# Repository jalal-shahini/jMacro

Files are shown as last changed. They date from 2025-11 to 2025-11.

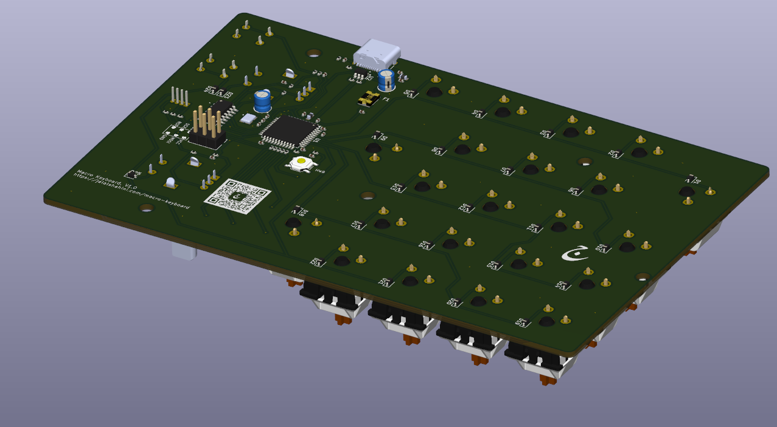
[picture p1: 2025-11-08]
3d_model_pcb_2.png

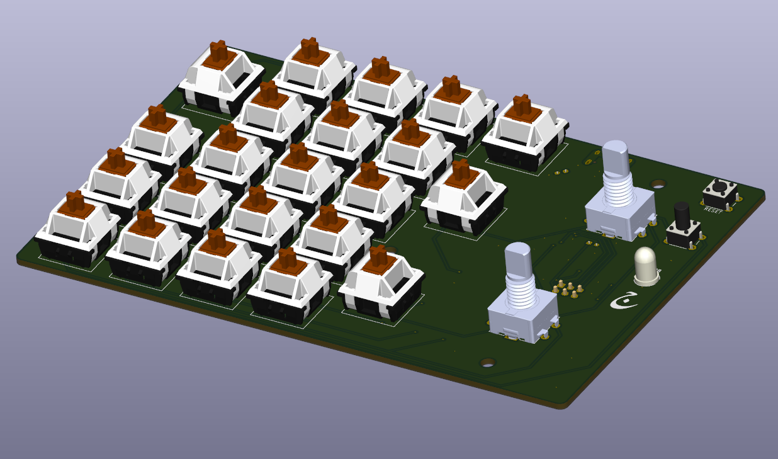
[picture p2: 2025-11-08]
3d_model_pcb.png

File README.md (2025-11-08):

# jMacro
## A Custom Built Macro Keyboard

This is a macro keyboard I designed to be:

1. a Numpad once a month when I need one.
2. an easy way to type the special characters I use constantly when taking notes such as ※, ℍ, Ω, ℚ, ∵, ∴, ℘ etc.
3. a life-saver when playing games.

The keyboard uses an Atmega32u4 microcontroller.
It features 22 keys with two rotary encoders with a Schmitt-trigger for a clean signal.

### To Do for a Future Version

* Single LED indicator is too bright and not ideal. I will use backlight LEDs for each individual key.
* Rotary encoders and USB circuit will benefit from a 4 layer PCB.
* Switches are better to be hot swappable.
* The electolytic capacitors are THT to save costs, however, in the next versions it is better to use all SMD components.

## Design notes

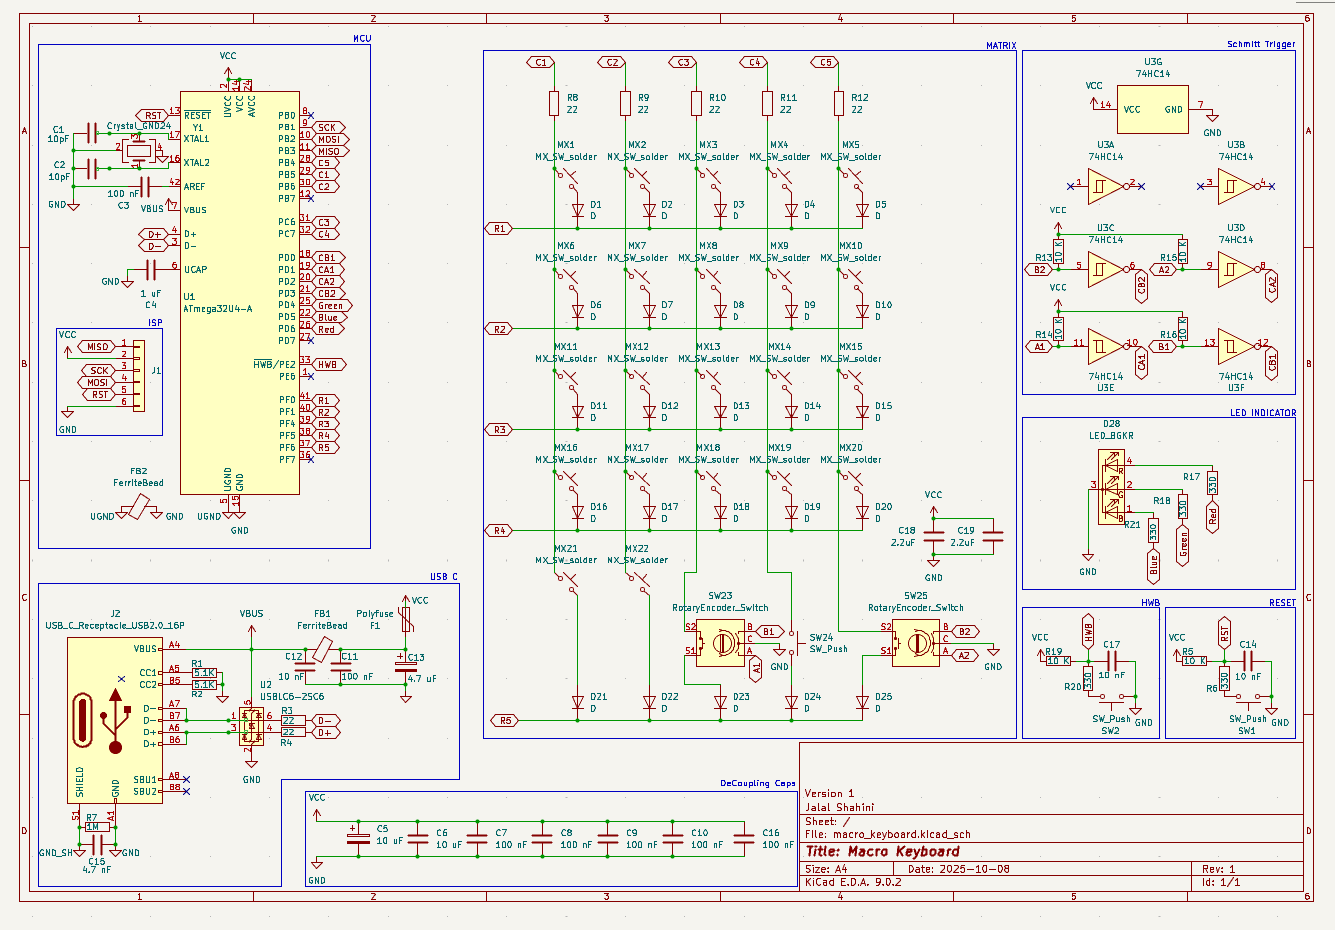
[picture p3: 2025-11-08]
schematic.png

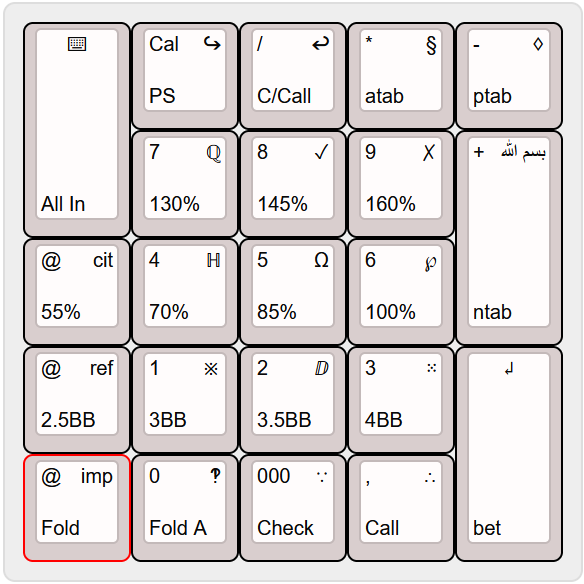
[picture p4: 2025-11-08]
layout.png

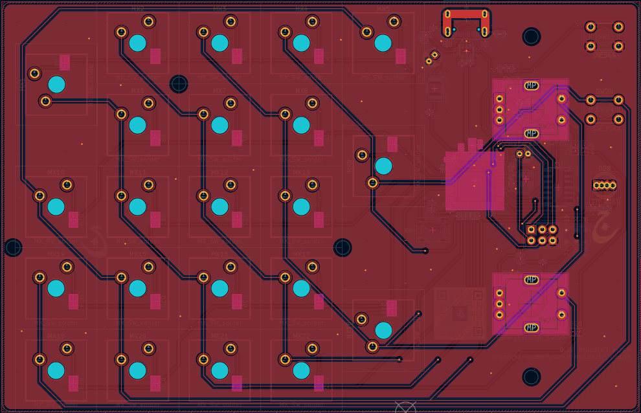
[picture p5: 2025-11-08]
top_layer.png

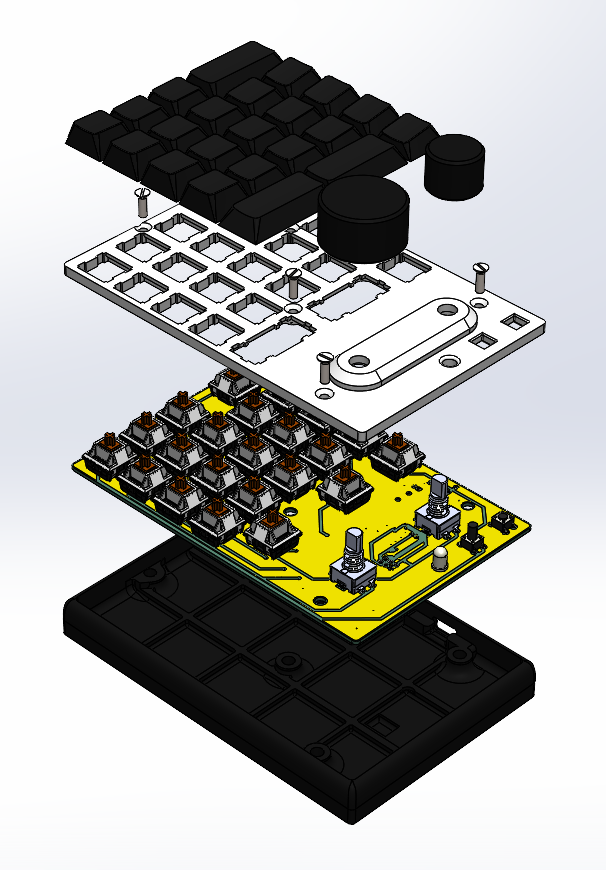
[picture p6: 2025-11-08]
exploded_view.png

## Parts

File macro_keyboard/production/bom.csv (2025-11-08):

Designator | Footprint | Quantity | Value | LCSC Part #
C1, C2 | 0402 | 2 | 10pF | C32949
C10, C11, C16, C7, C8, C9 | 0402 | 6 | 100 nF
C12 | 0402 | 1 | 10 nF
C14, C17 | 0402 | 2 | 10 nF
C15 | 0402 | 1 | 4.7 nF
C18, C19 | 0402 | 2 | 2.2uF
C3 | 0402 | 1 | 100 nF | C1525
C4 | 0402 | 1 | 1 uF
C6 | 0402 | 1 | 10 uF
D1, D10, D11, D12, D13, D14, D15, D16, D17, D18, D19, D2, D20, D21, D22, D23, D24, D25, D3, D4, D5, D6, D7, D8, D9 | D_SOD-323 | 25 | D | C2128
F1 | 1812 | 1 | Polyfuse | Manufacturer PTTC(Polytronics Tech) Copy MFR.Part # SMD1812P110TF Copy JLCPCB Part # C3102 Copy Package 1812 Copy Description -40℃~+85℃ 1.1A 100A 2.2A 210mΩ 300ms 40mΩ 800mW 8V 1812 Resettable Fuses ROHS
FB1, FB2 | BEADC1608X95N | 2 | FerriteBead | C14709
J2 | USB_C_Receptacle_HCTL_HC-TYPE-C-16P-01A | 1 | USB_C_Receptacle_USB2.0_16P | C2894897
R1, R2 | 0402 | 2 | 5.1K
R10, R11, R12, R3, R4, R8, R9 | 0402 | 7 | 22 | C25092
R13, R14, R15, R16, R19, R5 | 0402 | 6 | 10 K | C17414
R17, R18, R21 | 0402 | 3 | 330
R20, R6 | 0402 | 2 | 330 | C23138
R7 | 0402 | 1 | 1M
SW2 | SW_Push_1P1T_XKB_TS-1187A | 1 | SW_Push | C318884
U1 | TQFP-44_10x10mm_P0.8mm | 1 | ATmega32U4-A | C2052746
U2 | SOT-23-6 | 1 | USBLC6-2SC6 | C7519
U3 | SOIC-14_3.9x8.7mm_P1.27mm | 1 | 74HC14 | C5605
Y1 | OSC_X322516MLB4SI | 1 | Crystal_GND24 | C13738

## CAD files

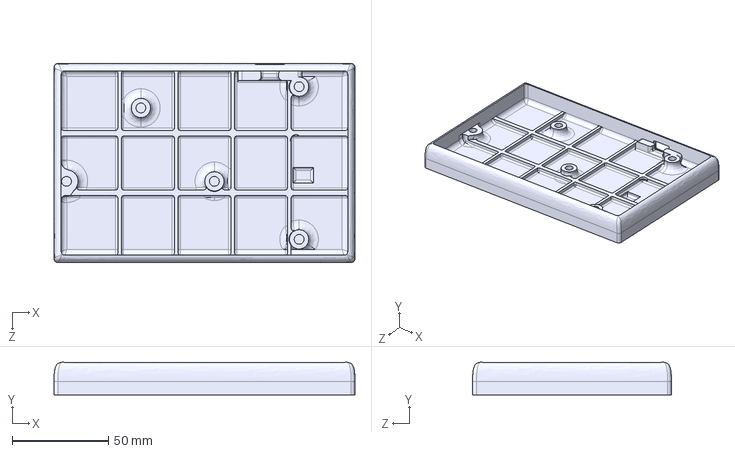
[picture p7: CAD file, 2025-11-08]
enclosure/Part2.STEP
156.3 x 17.0 x 103.2 mm

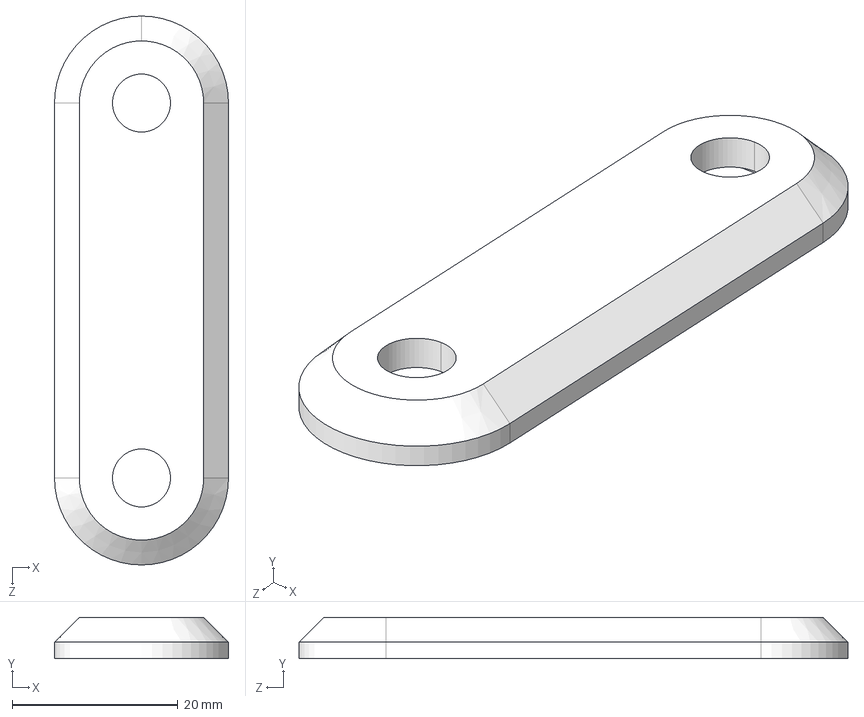
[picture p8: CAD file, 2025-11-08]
enclosure/Part3.STEP
21.0 x 5.00 x 66.2 mm

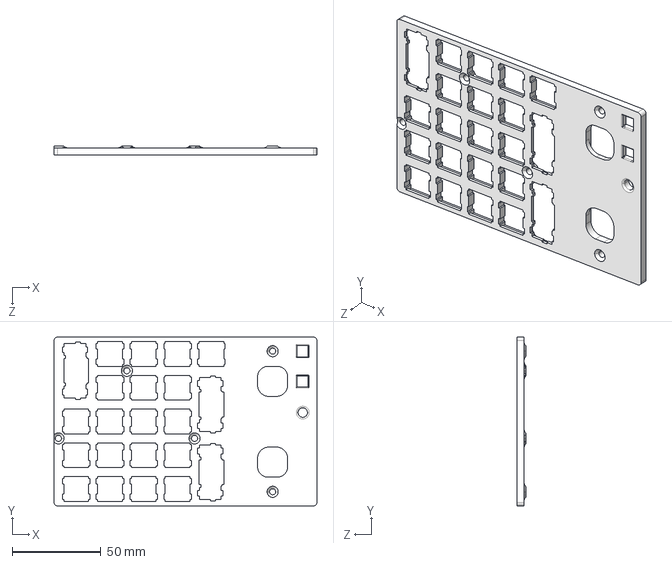
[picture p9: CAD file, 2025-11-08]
enclosure/Part1.STEP
148.3 x 95.2 x 5.00 mm

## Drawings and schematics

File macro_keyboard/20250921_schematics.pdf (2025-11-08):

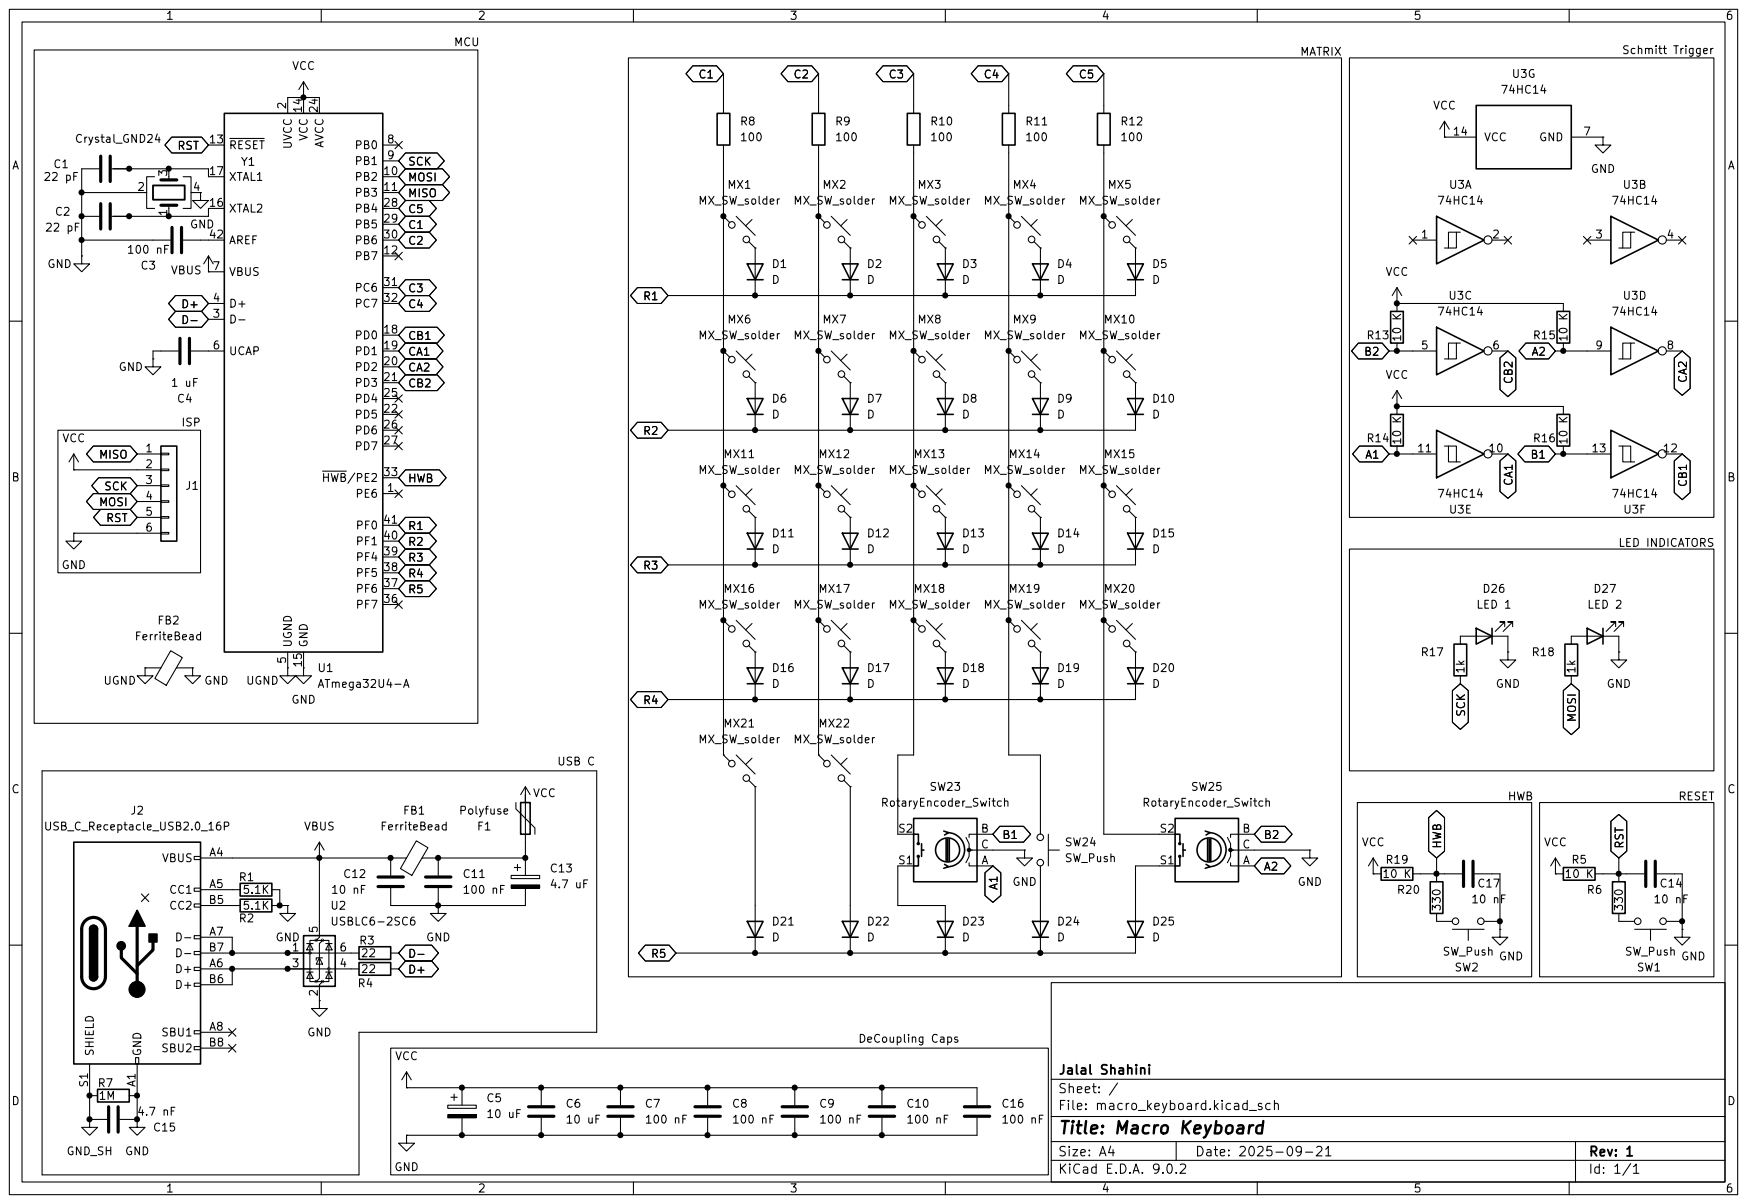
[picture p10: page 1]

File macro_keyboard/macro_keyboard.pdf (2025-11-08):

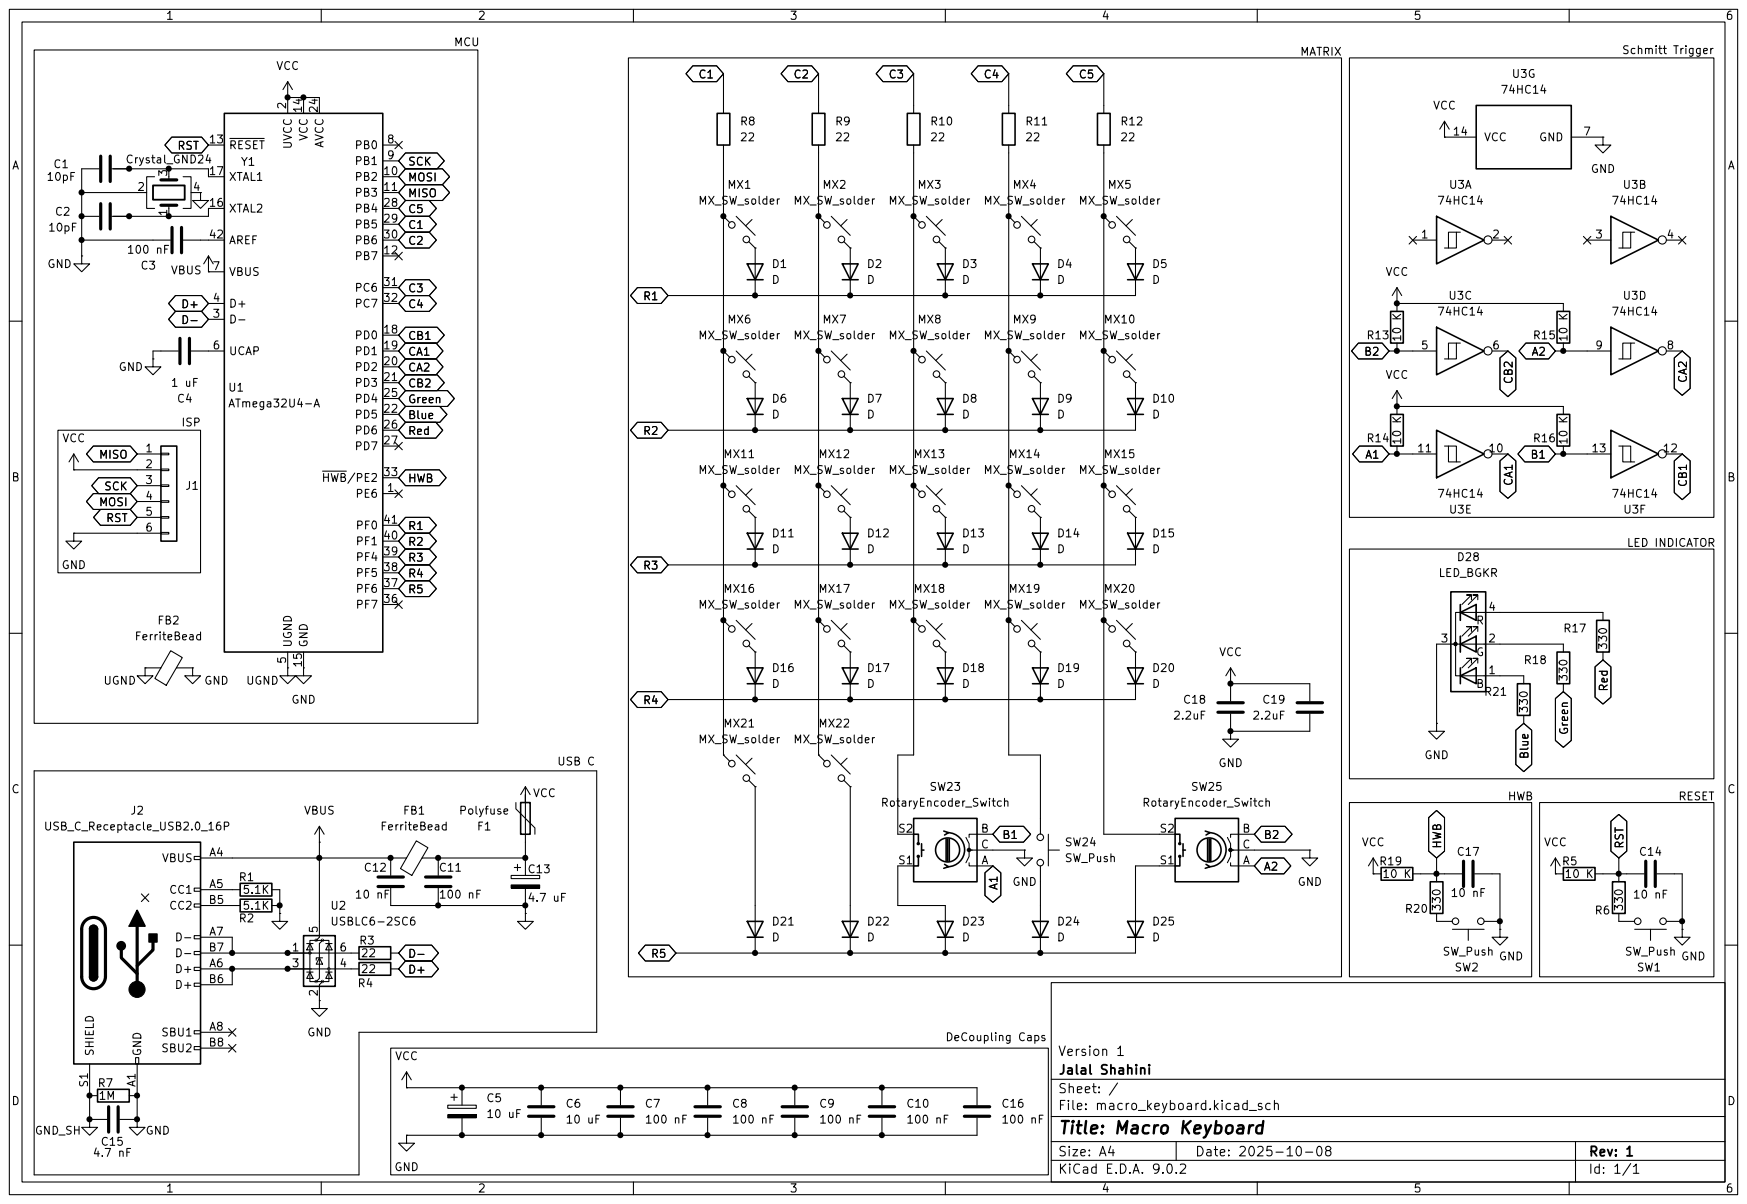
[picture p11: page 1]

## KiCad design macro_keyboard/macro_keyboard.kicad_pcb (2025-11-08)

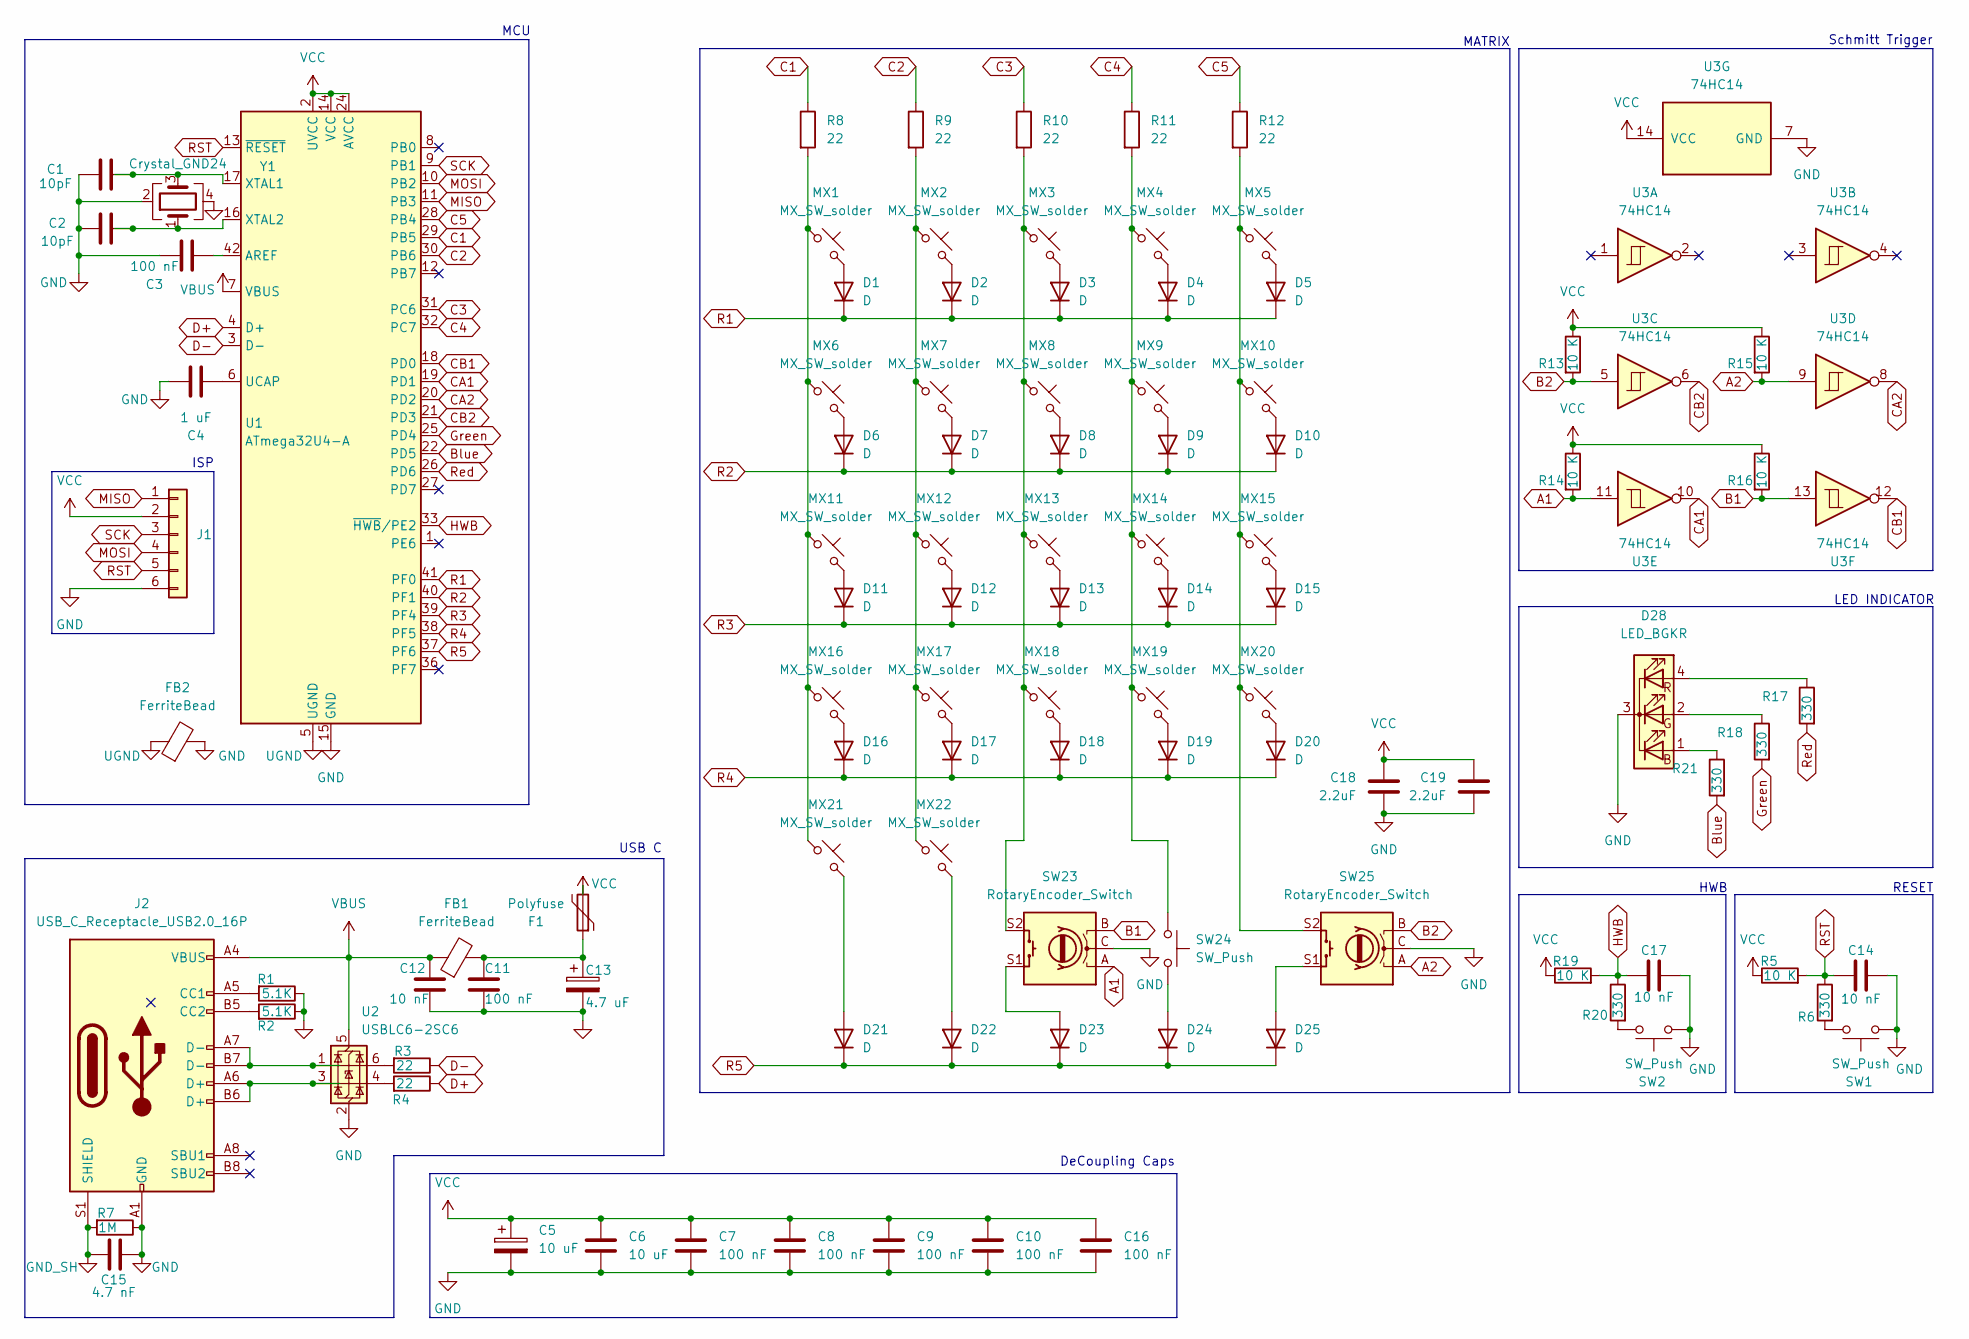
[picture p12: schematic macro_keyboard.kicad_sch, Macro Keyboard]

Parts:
C1, C2: 10pF; C_0402_1005Metric; LCSC C32949
C3, C7, C8, C9, C10, C11, C16: 100 nF; C_0402_1005Metric; LCSC C1525
C4: 1 uF; C_0402_1005Metric; LCSC C52923
C5: 10 uF; CP_Radial_D4.0mm_P2.00mm
C6: 10 uF; C_0402_1005Metric; LCSC C15525
C12, C14, C17: 10 nF; C_0402_1005Metric; LCSC C15195
C13: 4.7 uF; CP_Radial_D4.0mm_P2.00mm
C15: 4.7 nF; C_0402_1005Metric; LCSC C1538
C18, C19: 2.2uF; C_0402_1005Metric; LCSC C12530
D1, D2, D3, D4, D5, D6, D7, D8, D9, D10, D11, D12, D13, D14, D15, D16, D17, D18, D19, D20, D21, D22, D23, D24, D25: D; D_SOD-323; LCSC C2128
D28: LED_BGKR; LED_D5.0mm-4_RGB
F1: Polyfuse; Fuse_1812_4532Metric; LCSC C3102
FB1: FerriteBead; BEADC1608X95N; LCSC C14709
FB2: FerriteBead; C_0603_1608Metric; LCSC C14709
J1: Conn_01x06; PinHeader_2x03_P2.54mm_Vertical
J2: USB_C_Receptacle_USB2.0_16P; USB_C_Receptacle_HCTL_HC-TYPE-C-16P-01A; LCSC C2894897
MX1, MX2, MX3, MX4, MX5, MX6, MX7, MX8, MX9, MX10, MX11, MX12, MX13, MX14, MX15, MX16, MX17, MX18, MX19, MX20, MX21, MX22: MX_SW_solder; SW_Cherry_MX_Plate_1.00u
R1, R2: 5.1K; R_0402_1005Metric; LCSC C25905
R3, R4, R8, R9, R10, R11, R12: 22; R_0402_1005Metric; LCSC C25092
R5, R13, R14, R15, R16, R19: 10 K; R_0402_1005Metric; LCSC C25744
R6, R17, R18, R20, R21: 330; R_0402_1005Metric; LCSC C25104
R7: 1M; R_0402_1005Metric; LCSC C26083
SW1: SW_Push; SW_PUSH_6mm_H4.3mm
SW2: SW_Push; SW_Push_1P1T_XKB_TS-1187A; LCSC C318884
SW23, SW25: RotaryEncoder_Switch; RotaryEncoder_Alps_EC11E-Switch_Vertical_H20mm
SW24: SW_Push; SW_PUSH_6mm_H9.5mm
U1: ATmega32U4-A; TQFP-44_10x10mm_P0.8mm; LCSC C2052746
U2: USBLC6-2SC6; SOT-23-6; LCSC C7519
U3: 74HC14; SOIC-14_3.9x8.7mm_P1.27mm; LCSC C5605
Y1: Crystal_GND24; OSC_X322516MLB4SI; LCSC C13738

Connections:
A1: R14.2, SW23.A, U3.11
A2: R15.2, SW25.A, U3.9
B1: R16.2, SW23.B, U3.13
B2: R13.2, SW25.B, U3.5
Blue: R21.2, U1.22 (PD5)
C1: R8.1, U1.29 (PB5)
C2: R9.1, U1.30 (PB6)
C3: R10.1, U1.31 (PC6)
C4: R11.1, U1.32 (PC7)
C5: R12.1, U1.28 (PB4)
CA1: U1.19 (PD1), U3.10
CA2: U1.20 (PD2), U3.8
CB1: U1.18 (PD0), U3.12
CB2: U1.21 (PD3), U3.6
D+: R4.1, U1.4 (D+)
D-: R3.1, U1.3 (D-)
GND: C1.1, C2.1, C3.1, C4.2, C5.2, C6.2, C7.2, C8.2, C9.2, C10.2, C11.2, C12.2, C13.2, C14.2, C15.2, C16.2, C17.2, C18.2, C19.2, D28.3 (K), FB2.2, J1.6, J2.A1 (GND), J2.A12 (GND), J2.B1 (GND), J2.B12 (GND), R1.1, R2.1, R7.1, SW1.2, SW2.2, SW23.C, SW25.C, U1.15 (GND), U1.23 (GND), U1.35 (GND), U1.43 (GND), U2.2 (GND), U3.7 (GND), Y1.2, Y1.4
GND_SH: C15.1, J2.S1 (SHIELD), R7.2
Green: R18.2, U1.25 (PD4)
HWB: C17.1, R19.2, R20.1, U1.33 (~HWB/PE2)
MISO: J1.1, U1.11 (PB3)
MOSI: J1.4, U1.10 (PB2)
unnamed: C11.1, C13.1, F1.1, FB1.2
unnamed: D1.2 (A), MX1.2
unnamed: D2.2 (A), MX2.2
unnamed: D3.2 (A), MX3.2
unnamed: D4.2 (A), MX4.2
unnamed: D5.2 (A), MX5.2
unnamed: D6.2 (A), MX6.2
unnamed: D7.2 (A), MX7.2
unnamed: D8.2 (A), MX8.2
unnamed: D9.2 (A), MX9.2
unnamed: D10.2 (A), MX10.2
unnamed: D11.2 (A), MX11.2
unnamed: D12.2 (A), MX12.2
unnamed: D13.2 (A), MX13.2
unnamed: D14.2 (A), MX14.2
unnamed: D15.2 (A), MX15.2
unnamed: D16.2 (A), MX16.2
unnamed: D17.2 (A), MX17.2
unnamed: D18.2 (A), MX18.2
unnamed: D19.2 (A), MX19.2
unnamed: D20.2 (A), MX20.2
unnamed: D21.2 (A), MX21.2
unnamed: D22.2 (A), MX22.2
unnamed: D23.2 (A), SW23.S1
unnamed: D24.2 (A), SW24.2
unnamed: D25.2 (A), SW25.S1
unnamed: D28.1 (BA), R21.1
unnamed: D28.2 (GA), R18.1
unnamed: D28.4 (RA), R17.1
unnamed: J2.A5 (CC1), R1.2
unnamed: J2.B5 (CC2), R2.2
unnamed: J2.A6 (D+), J2.B6 (D+), U2.3 (I/O2)
unnamed: J2.A7 (D-), J2.B7 (D-), U2.1 (I/O1)
unnamed: MX1.1, MX6.1, MX11.1, MX16.1, MX21.1, R8.2
unnamed: MX5.1, MX10.1, MX15.1, MX20.1, R12.2, SW25.S2
unnamed: MX2.1, MX7.1, MX12.1, MX17.1, MX22.1, R9.2
unnamed: MX3.1, MX8.1, MX13.1, MX18.1, R10.2, SW23.S2
unnamed: MX4.1, MX9.1, MX14.1, MX19.1, R11.2, SW24.1
unnamed: R3.2, U2.6 (I/O1)
unnamed: R4.2, U2.4 (I/O2)
unnamed: R6.2, SW1.1
unnamed: R20.2, SW2.1
unnamed: C3.2, U1.42 (AREF)
unnamed: C4.1, U1.6 (UCAP)
unnamed: C1.2, U1.17 (XTAL1), Y1.3
unnamed: C2.2, U1.16 (XTAL2), Y1.1
R1: D1.1 (K), D2.1 (K), D3.1 (K), D4.1 (K), D5.1 (K), U1.41 (PF0)
R2: D6.1 (K), D7.1 (K), D8.1 (K), D9.1 (K), D10.1 (K), U1.40 (PF1)
R3: D11.1 (K), D12.1 (K), D13.1 (K), D14.1 (K), D15.1 (K), U1.39 (PF4)
R4: D16.1 (K), D17.1 (K), D18.1 (K), D19.1 (K), D20.1 (K), U1.38 (PF5)
R5: D21.1 (K), D22.1 (K), D23.1 (K), D24.1 (K), D25.1 (K), U1.37 (PF6)
RST: C14.1, J1.5, R5.2, R6.1, U1.13 (~RESET)
Red: R17.2, U1.26 (PD6)
SCK: J1.3, U1.9 (PB1)
UGND: FB2.1, U1.5 (UGND)
VBUS: C12.1, FB1.1, J2.A4 (VBUS), J2.A9 (VBUS), J2.B4 (VBUS), J2.B9 (VBUS), U1.7 (VBUS), U2.5 (VBUS)
VCC: C5.1, C6.1, C7.1, C8.1, C9.1, C10.1, C16.1, C18.1, C19.1, F1.2, J1.2, R5.1, R13.1, R14.1, R15.1, R16.1, R19.1, U1.2 (UVCC), U1.14 (VCC), U1.24 (AVCC), U1.34 (VCC), U1.44 (AVCC), U3.14 (VCC)

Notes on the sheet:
RESET
HWB
DeCoupling Caps
ISP
USB C
MATRIX
MCU
Schmitt Trigger
LED INDICATOR

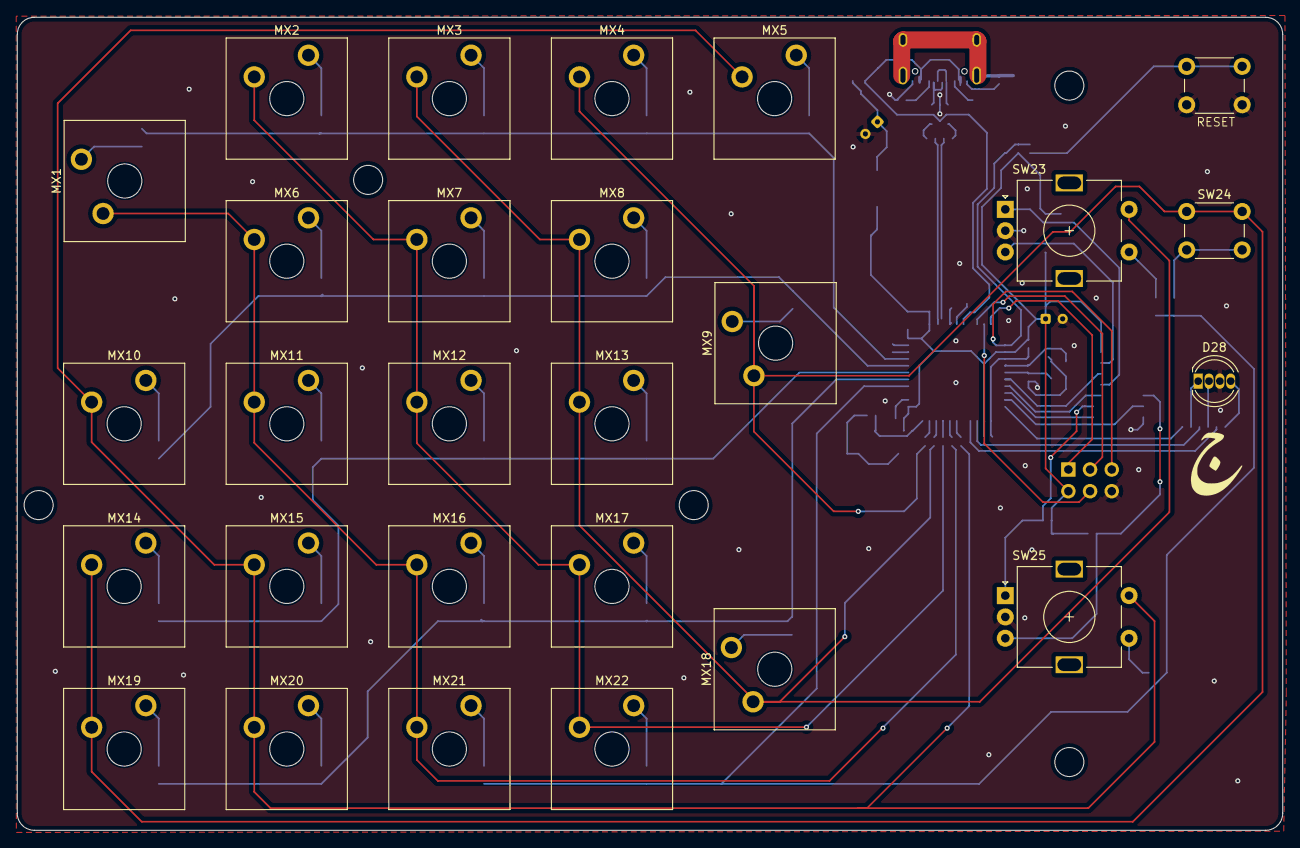
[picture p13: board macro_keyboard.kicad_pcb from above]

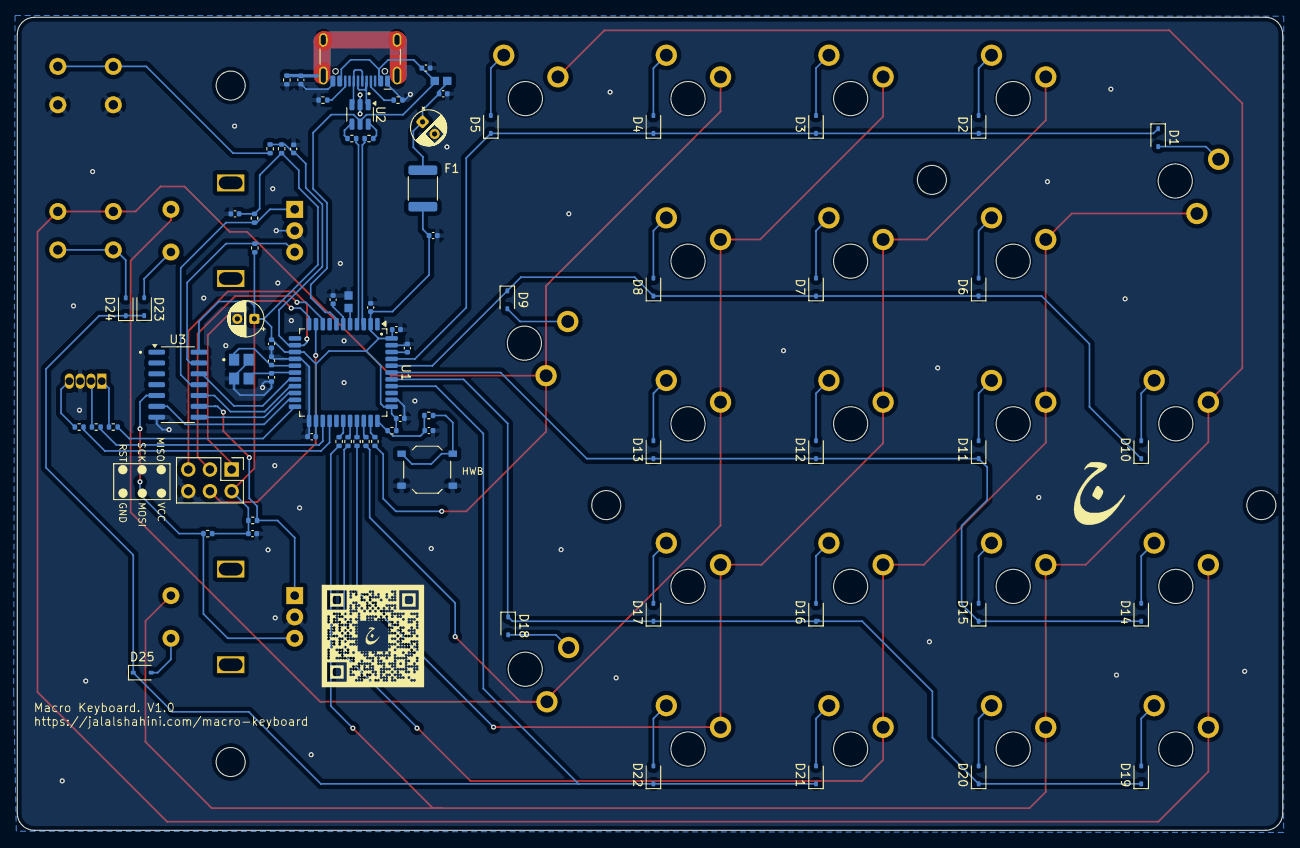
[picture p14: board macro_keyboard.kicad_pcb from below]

Board: 2 copper layers, 148.3 x 95.3 mm, 102 parts (75 on the bottom side), 79 nets.

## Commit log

2025-11-08 version 1.0
    [Part1.STEP, Part2.STEP, Part3.STEP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]
2025-11-09 encoder layer function
